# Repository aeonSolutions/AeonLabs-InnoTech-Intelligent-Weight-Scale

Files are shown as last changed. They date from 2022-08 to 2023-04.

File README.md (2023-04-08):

[PCB-Prototyping-Catalogue](https://github.com/aeonSolutions/PCB-Prototyping-Catalogue)  >>  [Home-Automation](https://github.com/aeonSolutions/PCB-Prototyping-Catalogue/tree/main/Home-Automation)  >>  [Smart Home Appliances](https://github.com/aeonSolutions/PCB-Prototyping-Catalogue/tree/main/Home-Automation/Smart%20Home%20Appliances)  >>  [Bathroom](https://github.com/aeonSolutions/PCB-Prototyping-Catalogue/tree/main/Home-Automation/Smart%20Home%20Appliances/bathroom) >>  InnoTech Intelligent Weight Scale

<br>


  
 
 

<a href="https://trackgit.com">
trackgit-views
</a>


<br />

# AeonLabs InnoTech Intelligent Weight Scale
This smart PCB is a direct replacement of the one that is installed on all InnoTech Weight Scales. Features a color LCD and you can connect to your home automation without the need for third-party cloud storage. **This way your health data never leaves your home**.

A breif view of the original specifications:

- Innotech Smart scale analyze 9 essential measurements of your body, including weight, body fat, water, muscle mass, BMI, BMR, visceral fat, bone mass, and protein. Data easily transferred to the Innotech Scale APP as well as other partners' APPs, it will keep you informed about your body data
- Innotech BMI scale can track the measurement for up to 10 users. Innotech Body Fat Scale helps to track and obtain your family’s daily measurements. This Smart Scale is perfect for family, body builder, weight loser
- 4 built-in sensors that ensure accurate measurement up to 397 lbs/180kg in 0.2 lb/0.1kg increments. Our stylish smart scale boosts an extended surface area with resilient tempered glass for durability. The large LED screen easily displays weight without your mobile device

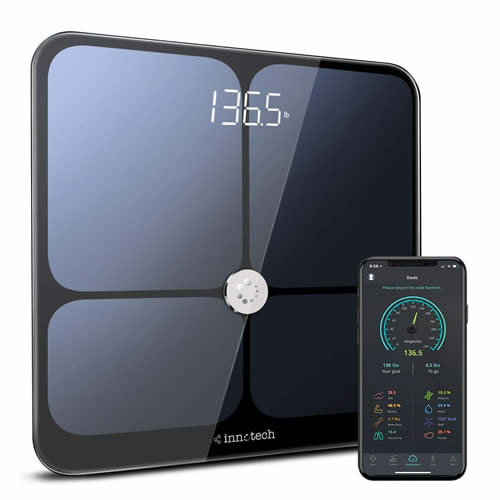
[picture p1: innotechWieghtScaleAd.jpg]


## PCB


## What one additionally needs
- [USB to UART/USB TTL firmware burner for 5V and 3.3V MCUs ](https://github.com/aeonSolutions/PCB-Prototyping-Catalogue/blob/main/DIY-Maker/README.md) 
<br />
<br />

## Author

You can get in touch with me on my LinkedIn Profile:

#### Miguel Tomas



You can also follow my GitHub Profile to stay updated about my latest projects: 

<br>

### Be supportive of my dedication and work towards technology education and buy me a cup of coffee
The PCB Desgin Files i provide here for anyone to use are free. If you like this Smart Device or use it, please consider buying me a cup of coffee, a slice of pizza or a book to help me study, eat and think new PCB design files.

[](https://www.buymeacoffee.com/migueltomas)

<br />

### Make a donation on Paypal
Make a donation on paypal and get a TAX refund*.

(http://paypal.me/mtpsilva)

<br>

### Support all these open hardware projects and become a patreon  
Liked any of my PCB KiCad Designs? Help and Support my open work to all by becomming a LDAD Patreon.
In return I will give a free PCB design in KiCad to all patreon supporters. To learn more go to patreon.com. Link below.

(https://www.patreon.com/ldad)

<br />
<br />

______________________________________________________________________________________________________________________________
### License
2023 Creative Commons Attribution-NonCommercial-ShareAlike 4.0 International

https://creativecommons.org/licenses/by-nc-sa/4.0/

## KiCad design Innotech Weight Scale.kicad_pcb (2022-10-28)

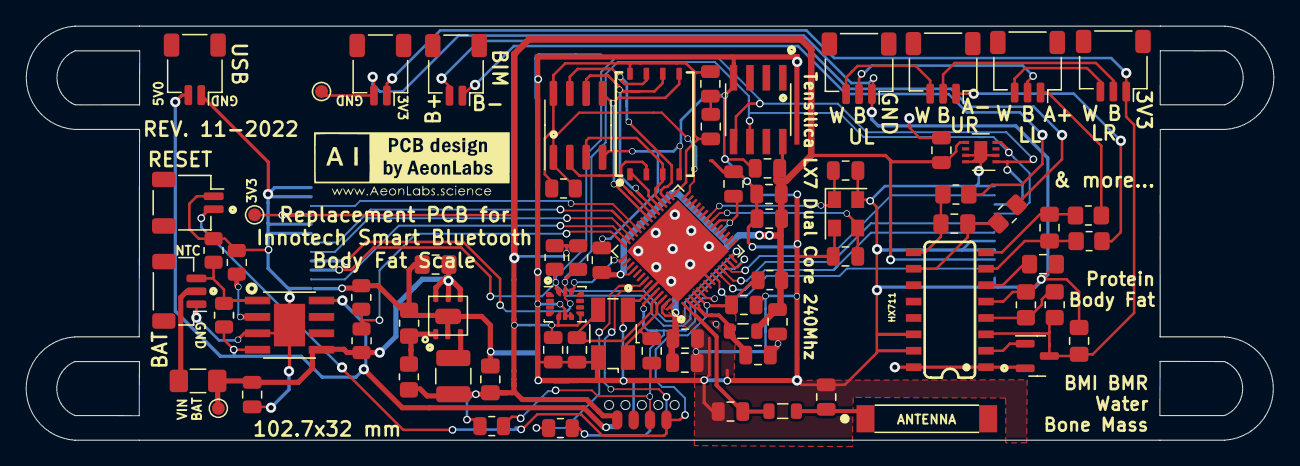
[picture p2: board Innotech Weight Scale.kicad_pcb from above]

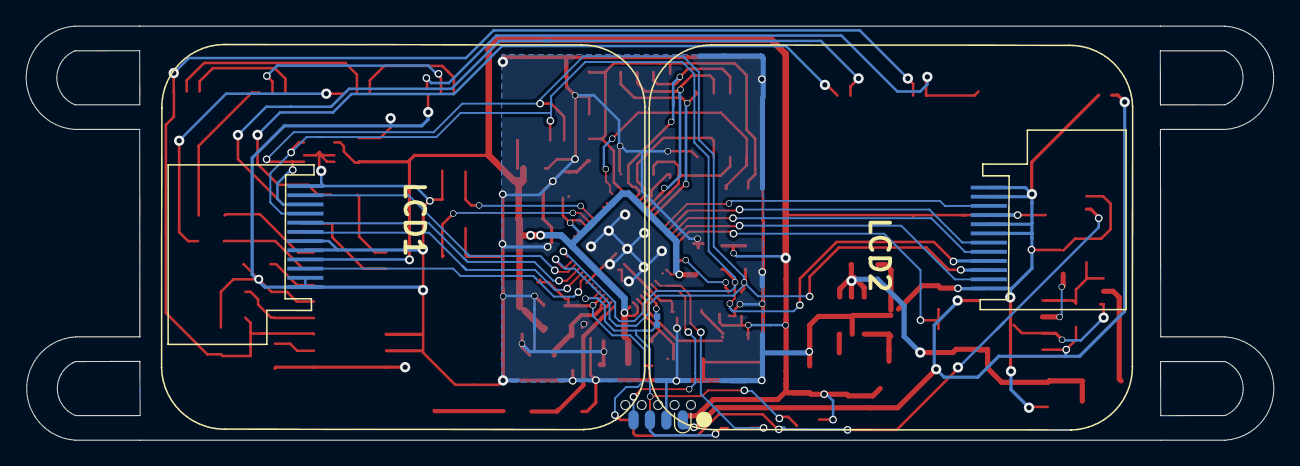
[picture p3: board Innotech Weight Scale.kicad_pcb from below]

Board: 2 copper layers, 96.6 x 32.1 mm, 78 parts (3 on the bottom side), 58 nets.

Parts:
2TY1: S8550; SOT-23
AC1: 22uF; C_0805_2012Metric_Pad1.18x1.45mm_HandSolder
AC2: 4.7uF; C_0805_2012Metric_Pad1.18x1.45mm_HandSolder
AL1: 3.3uF; L_1210_3225Metric
ANT1: AN9520; AN9520_ANT2-SMD-9.5X2.1X1.0MM
AR1: 47K; R_0805_2012Metric_Pad1.20x1.40mm_HandSolder
AR2: 15K; R_0805_2012Metric_Pad1.20x1.40mm_HandSolder
AU1: AUR9718x_DFN_3x3mm_6_pin; AUR9718 3x3mm 6 pin
AUC1: 100nF; C_0805_2012Metric
BAT2: BAT1; JST_SH_BM03B-SRSS-TB_1x03-1MP_P1.00mm_Vertical
BMI1: Screw_Terminal_01x02; JST_SH_SM02B-SRSS-TB_1x02-1MP_P1.00mm_Horizontal
BMIPW1: Screw_Terminal_01x02; JST_SH_SM02B-SRSS-TB_1x02-1MP_P1.00mm_Horizontal
EC12, EC13, EC50, EC51: 22pF 5% 50V; C_0805_2012Metric
EC14: 100pF; C_0805_2012Metric
EC15, EC25: 1uF 10% 50V; C_0805_2012Metric
EC16, EC19, EC20, EC24, EC26, EC37, EC38: 100nF 10% 16V; C_0805_2012Metric
EC17, EC18: 10uF 20% 6.3V; C_0805_2012Metric
EC40: 100nF; C_0805_2012Metric
ECY1: 40Mhz 22pF+-10PPM; Crystal_SMD_EuroQuartz_MJ-4Pin_5.0x3.2mm
ECY2: 32.768Mhz 22pF+-10PPM; Crystal_SMD_EuroQuartz_MT-4Pin_3.2x2.5mm
EL4: 12nH 5%; L_0805_2012Metric
EPS1: ESP32-PSRAM_LY68L6400S; SOIC-8_3.9x4.9mm_P1.27mm
ER1, ER3: 10k; R_0805_2012Metric
ER2: 499R; R_0805_2012Metric
ESP32S3: ESP32-S3; QFN-56-1EP_7x7mm_P0.4mm_EP5.6x5.6mm
ESP_FLASH1: W25Q128JVS; W25Q128JV WSON 8x6-mm
F1: Polyfuse; Fuse_1206_3216Metric_Pad1.42x1.75mm_HandSolder
HC1, HC2, HC4: 0.1pF; C_0805_2012Metric_Pad1.18x1.45mm_HandSolder
HC3: 10pF; C_0805_2012Metric_Pad1.18x1.45mm_HandSolder
HR1, HR2, HR5, HR6: 100R; R_0805_2012Metric_Pad1.20x1.40mm_HandSolder
HR3: 8.4k; R_0805_2012Metric_Pad1.20x1.40mm_HandSolder
HR4: 18k4; R_0805_2012Metric_Pad1.20x1.40mm_HandSolder
HX711: HX711; HX711 SO16
ICR1: 10k; R_0805_2012Metric
ICSP1: Conn_01x08_Male; SOIC_clipProgSmall
IDR1: 10k; R_0805_2012Metric
IMU1: LSM6DS3; LGA-14_3x2.5mm_P0.5mm_LayoutBorder3x4y
IMUC1: 100nF; C_0805_2012Metric
L2: 12nH 5%; L_0805_2012Metric
LCD1, LCD2: Conn_01x12_Male; 1,69 inch LCD IPS TFT
LL4: Screw_Terminal_01x03; JST_SH_SM03B-SRSS-TB_1x03-1MP_P1.00mm_Horizontal
LR1: Screw_Terminal_01x03; JST_SH_SM03B-SRSS-TB_1x03-1MP_P1.00mm_Horizontal
MR3: 390K; R_0805_2012Metric
MR4: 110K; R_0805_2012Metric
PSR1: 100K; R_0805_2012Metric
RST1: Conn_01x02_Female; JST_SH_SM02B-SRSS-TB_1x02-1MP_P1.00mm_Horizontal
SH1: SHT31-DIS; Sensirion_DFN-8-1EP_2.5x2.5mm_P0.5mm_EP1.1x1.7mm
SHC1: 100nF; C_0805_2012Metric
TP1: VIN; TestPoint_Pad_D1.0mm
TP2: VOut; TestPoint_Pad_D1.0mm
TP3: GND; TestPoint_Pad_D1.0mm
TPC2: 10uF; C_0805_2012Metric
TPR1, TPR2, TPR3: 1k2; R_0805_2012Metric
TPU1: TP4056; SOP127P600X175-9N TP4056
U2: ATSHA204A-MAHDA-T; ATSHA204A Auth SOIC8
UL2: Screw_Terminal_01x03; JST_SH_SM03B-SRSS-TB_1x03-1MP_P1.00mm_Horizontal
UR3: Screw_Terminal_01x03; JST_SH_SM03B-SRSS-TB_1x03-1MP_P1.00mm_Horizontal
USBCHR1: Screw_Terminal_01x02; JST_SH_SM02B-SRSS-TB_1x02-1MP_P1.00mm_Horizontal

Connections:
3V3: AC1.1, AL1.1, AR1.1, AUC1.2, EC14.2, EC15.2, EC16.1, EC17.1, EC18.1, EC19.1, EC26.1, ER1.1, ER3.1, ESP32S3.20 (VDD3P3_RTC), ESP32S3.46 (VDD3P3_CPU), ESP32S3.55 (VDDA), ESP32S3.56 (VDDA), ICR1.1, ICSP1.8, IDR1.2, IMU1.5 (VDDIO), IMU1.8 (VDD), IMUC1.2, L2.1, LCD1.4, LCD2.4, SH1.5 (VDD), SHC1.2, TP2.1, U2.8 (VCC)
5V0: ICSP1.1, TPR3.2, TPU1.4 (VCC), TPU1.8 (CE), USBCHR1.2
BAT_NTC: BAT2.3, TPR2.2, TPR3.1, TPU1.1 (TEMP)
BAT_SENSE_IO37: ESP32S3.42 (GPIO37), MR3.2, MR4.1
CHIP_EN: EC40.2, ER1.2, ESP32S3.4 (CHIP_PU/RESET), ICSP1.5, RST1.2
ESP_GPIO0_BOOT-DTR: ER3.2, ESP32S3.5 (GPIO0/BOOT), ESP32S3.52 (GPIO46), ICSP1.6
GND: AC1.2, AC2.2, AR2.2, AU1.2 (GND), AUC1.1, BAT2.1, BMIPW1.2, EC12.2, EC13.2, EC14.1, EC15.1, EC16.2, EC17.2, EC18.2, EC19.2, EC20.2, EC24.2, EC25.2, EC26.2, EC37.2, EC38.2, EC40.1, EC50.2, EC51.2, ECY1.2, ECY1.4, ECY2.2, ECY2.4, EPS1.4 (VSS), ESP32S3.8 (GPIO3/ADC1_CH2), ESP32S3.51 (GPIO45), ESP32S3.57 (GND), ESP_FLASH1.4 (GND), HC2.2, HC3.1, HR3.2, HX711.5 (AGND), HX711.14 (XI), HX711.15 (RATE), ICSP1.2, IMU1.6 (GND), IMU1.7 (GND), IMUC1.1, LCD1.1, LCD1.2, LCD1.5, LCD1.6, LCD1.12, LCD2.1, LCD2.2, LCD2.5, LCD2.6, LCD2.12, MR4.2, RST1.1, SH1.2 (ADDR), SH1.7 (R), SH1.8 (VSS), SH1.9 (VSS), SHC1.1, TP3.1, TPC2.2, TPR1.1, TPR2.1, TPU1.3 (GND), TPU1.9 (EP), U2.4 (GND), UL2.1, USBCHR1.1
GPIO8_I2C_SDA: ESP32S3.13 (GPIO8/ADC1_CH7), IDR1.1, IMU1.14 (SDA), LCD1.10, LCD2.10, SH1.1 (SDA), U2.5 (SDA)
GPIO9_I2C_SCL: ESP32S3.14 (GPIO9/ADC1_CH8), ICR1.2, IMU1.13 (SCL), LCD1.9, LCD2.9, SH1.4 (SCL), U2.6 (SCL)
HX_3V3: 2TY1.3 (C), BMIPW1.1, HC3.2, HR4.2, HX711.3 (AVDD), LR1.1
HX_3V3_IO: 2TY1.2 (E), HX711.1 (VSUP), HX711.16 (DVDD)
HX_A+: HR1.2, LL4.1
HX_A-: HR2.2, UR3.1
HX_B+: BMI1.2, HR5.2
HX_B-: BMI1.1, HR6.2
IMU_CS_IO38: ESP32S3.43 (GPIO38), IMU1.12 (CS)
LCD1_CS_IO06: ESP32S3.11 (GPIO6/ADC1_CH5), LCD1.8
LCD1_DC_IO05: ESP32S3.10 (GPIO5/ADC1_CH4), LCD1.7
LCD1_LED_IO04: ESP32S3.9 (GPIO4/ADC1_CH3), LCD1.3
LCD1_RESET_IO07: ESP32S3.12 (GPIO7/ADC1_CH6), LCD1.11
LCD2_CS_IO35: ESP32S3.40 (GPIO35), LCD2.8
LCD2_DC_IO34: ESP32S3.39 (GPIO34), LCD2.7
LCD2_LED_IO33: ESP32S3.38 (GPIO33), LCD2.3
LCD2_RESET_IO36: ESP32S3.41 (GPIO36), LCD2.11
unnamed: 2TY1.1 (B), HX711.2 (BASE)
unnamed: AL1.2, AU1.3 (SW)
unnamed: ANT1.1, EC37.1, EL4.1
unnamed: AR1.2, AR2.1, AU1.1 (FB)
unnamed: EC12.1, ECY1.1, ESP32S3.54 (XTAL_P)
unnamed: EC13.1, ECY1.3, ESP32S3.53 (XTAL_N)
unnamed: EC20.1, ESP32S3.2 (VDD3P3), ESP32S3.3 (VDD3P3), L2.2
unnamed: EC38.1, EL4.2, ESP32S3.1 (LNA_IN/RF)
unnamed: EC50.1, ECY2.1, ESP32S3.22 (GPIO16/ADC2_CH5/XTAL_32K_N)
unnamed: EC51.1, ECY2.3, ESP32S3.21 (GPIO15/ADC2_CH4/XTAL_32K_P)
unnamed: ER2.2, ESP32S3.49 (U0TXD/PROG/GPIO43)
unnamed: HC1.1, HR2.1, HX711.7 (INA-)
unnamed: HC1.2, HR1.1, HX711.8 (INA+)
unnamed: HC2.1, HX711.6 (VBG)
unnamed: HC4.1, HR5.1, HX711.10 (INB+)
unnamed: HC4.2, HR6.1, HX711.9 (INB-)
unnamed: HR3.1, HR4.1, HX711.4 (VFB)
unnamed: LL4.2, UL2.2
unnamed: LL4.3, LR1.3
unnamed: LR1.2, UR3.2
unnamed: TPR1.2, TPU1.2 (PROG)
unnamed: UL2.3, UR3.3
RXD0: ESP32S3.50 (U0RXD/PROG/GPIO44), ICSP1.4
SPICLK: EPS1.6 (SCLK), ESP32S3.33 (SPICLK/GPIO30), ESP_FLASH1.6 (CLK)
SPICS0: ESP32S3.32 (SPICS0/GPIO29), ESP_FLASH1.1 (~CS)
SPICS1: EPS1.1 (~CE), ESP32S3.28 (SPI_CS1/GPIO26), PSR1.1
SPID: EPS1.5 (SiO0), ESP32S3.35 (SPID/GPIO32), ESP_FLASH1.5 (DI(IO0))
SPIHD: EPS1.7 (SIO3), ESP32S3.30 (SPIHD/GPIO27), ESP_FLASH1.7 (IO3)
SPIQ: EPS1.2 (SIO1), ESP32S3.34 (SPIQ/GPIO31), ESP_FLASH1.2 (DO(IO1))
SPIWP: EPS1.3 (SIO2), ESP32S3.31 (SPIWP/GPIO28), ESP_FLASH1.3 (IO2)
TXD0: ER2.1, ICSP1.3
VDD_SPI: EC24.1, EC25.1, EPS1.8 (VCC), ESP32S3.29 (VDD_SPI), ESP_FLASH1.8 (VCC), PSR1.2
VIN_BAT: AC2.1, AU1.4 (VIN_SW), AU1.5 (VIN_A), AU1.6 (EN), F1.1, MR3.1, TP1.1, TPC2.1, TPU1.5 (BAT)
VIN_BATF: BAT2.2, F1.2
